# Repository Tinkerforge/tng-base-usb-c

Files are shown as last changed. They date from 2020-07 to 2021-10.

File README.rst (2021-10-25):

TNG Base USB C
==============

**This TNG module is currently in development.**

This repository contains the firmware source code and the hardware design
files. The documentation generator configs can be found at
https://github.com/Tinkerforge/generators

Repository Content
------------------

software/:
 * examples/: Examples for all supported languages
 * build/: Compiled files
 * src/: Source code of firmware
 * Makefile: Makefile to build project

hardware/:
 * Contains KiCad project files and additionally schematics as PDF

datasheets/:
 * Contains datasheets for sensors and complex ICs that are used

Hardware
--------

The hardware is designed with the open source EDA Suite KiCad
(http://www.kicad.org). Before you are able to open the files,
you have to install the Tinkerforge kicad-libraries
(https://github.com/Tinkerforge/kicad-libraries). You can either clone
them directly in hardware/ or clone them in a separate folder and
symlink them into hardware/
(ln -s kicad_path/kicad-libraries project_path/hardware). After that you
can open the .pro file in hardware/ with KiCad and from there view and
modify the schematics and the PCB layout.

Software
--------

If you want to do your own Brick/Bricklet firmware development we highly
recommend that you use our build environment setup script and read the
tutorial (https://www.tinkerforge.com/en/doc/Tutorials/Tutorial_Build_Environment/Tutorial.html).

To compile the C code we recommend you to install the newest GNU Arm Embedded
Toolchain (https://launchpad.net/gcc-arm-embedded/+download).
You also need to install bricklib2 (https://github.com/Tinkerforge/bricklib2).

You can either clone it directly in software/src/ or clone it in a
separate folder and symlink it into software/src/
(ln -s bricklib_path/bricklib2 project_path/software/src/). Finally make sure to
have CMake installed (http://www.cmake.org/cmake/resources/software.html).

After that you can build the firmware by invoking make in software/.
The firmware (.zbin) can then be found in software/build/ and uploaded
with brickv (click button "Flashing" on start screen).

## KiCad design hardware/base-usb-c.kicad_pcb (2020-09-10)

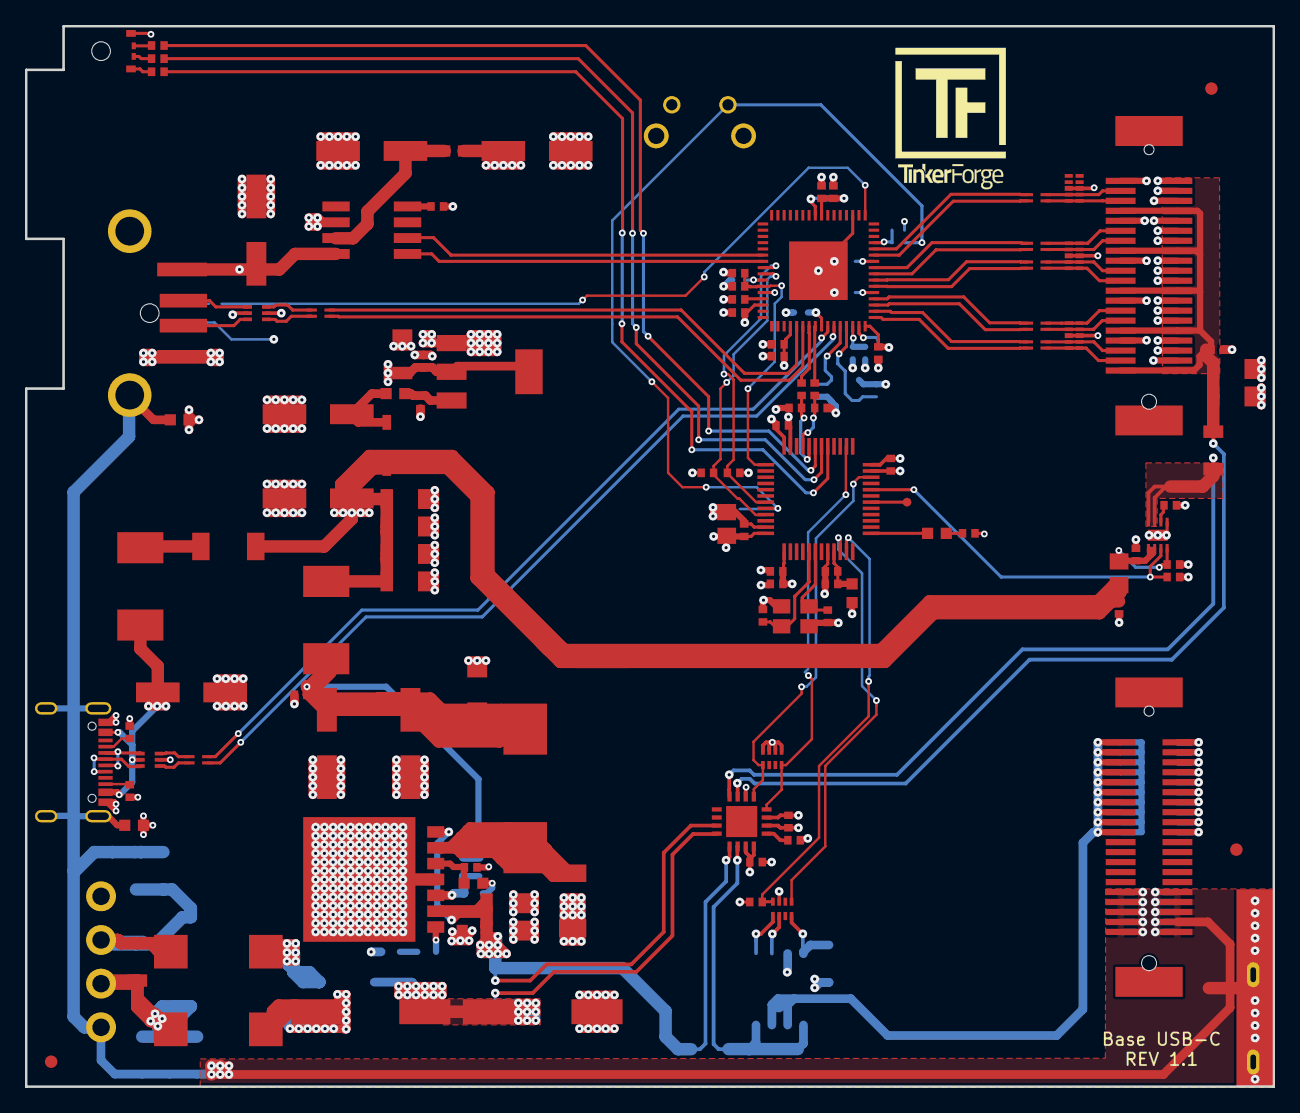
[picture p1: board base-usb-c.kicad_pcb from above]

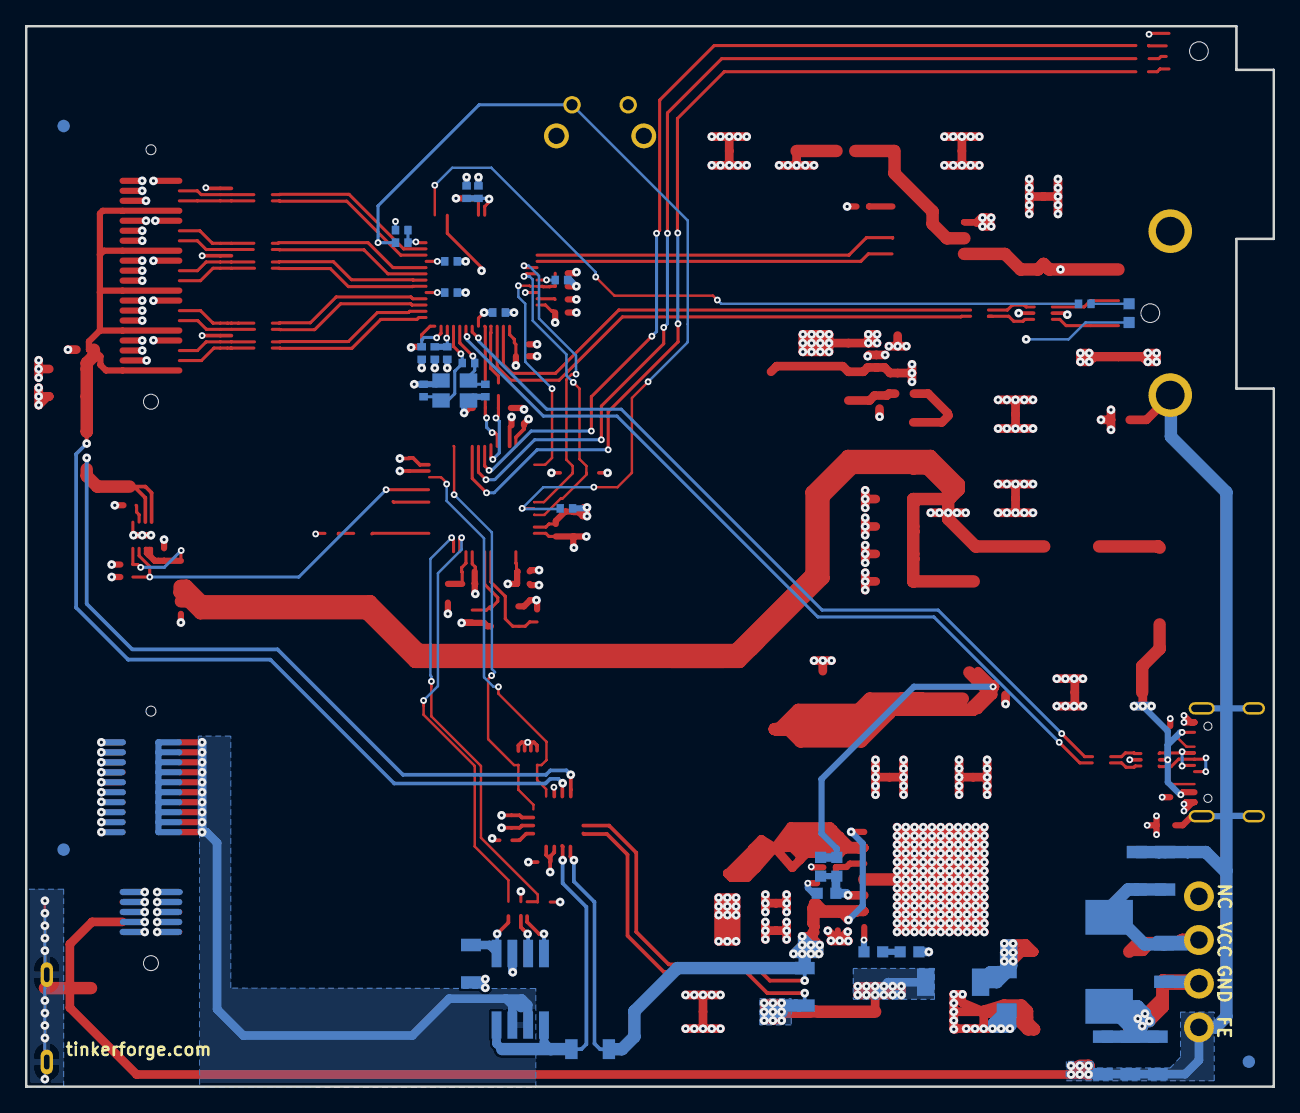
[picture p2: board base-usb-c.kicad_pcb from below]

Board: 4 copper layers, 100.0 x 85.0 mm, 157 parts (39 on the bottom side), 103 nets.

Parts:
C101, C102, C137, C138: 33pF; C0402F
C103, C105, C115, C119, C123, C124, C125, C126, C128, C134, C209, C226: 1uF; C0402F
C104, C106, C107, C110, C111, C112, C113, C114, C116, C118, C127, C129, C130, C131, C133, C214, C221, C222: 100nF; C0402F
C108, C109, C117, C141, C203, C216, C219, C220: 100uF; ELKO_63
C120, C140, C205: 100nF; C0603F
C121, C122: 47pF; C0402F
C132: DNP; C0402F
C135, C136, C201, C202, C215, C218, C223, C224, C225, C227: 10uF; C1206
C139: 10uF; C0805E
C204, C211: 10nF; C1206
C206, C207: 1nF 2kV; C1206
C208: 100pF; C0402F
C210: 4.7nF; C0603F
C212, C213: UWT1H221MNL1GS; ELKO_103
C217: DNP; C0603F
D101: LED green; LED-LP
D102: LED; D0603F
D201: 3.0SMI30CATR; SMC
D202, D205, D206: PMEG6045; SOD-128
D203: B0520LW-7-F; SOD-123
Fiducial_Mark: VAL**; Fiducial_Mark
Fiducial_Mark#2, Fiducial_Mark#3, Fiducial_Mark#4, Fiducial_Mark#5, Fiducial_Mark#6: VAL**; Fiducial_Mark
J101: USB-A; USB-A-SMT-8231
J102: USB-C; USB-C-2
J103: TNG-Power-TOP; TNG-40-TOP
J105: TNG-Data-TOP; TNG-40-TOP
L101, L201: INDUCTs; R0603F
L102, L103, L104, L105, L106, L107, L110: 744230900; WE-CNSW-0603
L108: FB; R0603F
L109: 742792040; R0805E
L111, L203: 10uH; SRP7030
L202: 22uH 74437368220; WE-LHMI
LED101: EASV3015RGBA0; LED-RGB-LP
P101: Debug; DEBUG_PAD
P102: PE; PE_Hook
P202: PWR IN; OQ_4P
R101, R105, R106, R107, R109, R111, R116, R117, R218: 10k; R0402F
R102: 100k; R0402F
R103: 1M; R0402F
R104, R108, R114, R121: 1k; R0402F
R110: 12k; R0402F
R112, R113: 22; R0402F
R115, R119: 0; R0402F
R118: 1k; R1206
R120: 56; R0402F
R122, R123: 5k1; R0402F
R204, R206, R207: VC1206K201R030; R1206
R208: 27k; R0603F
R209: 1M; R1206
R212: 20k; R0603F
R214: 47k; R0603F
R215: 8.2k; R0603F
R219, R220, R221: 0.02; R1206
RP102, RP201: 10k; 4X0402
SW101: BOOT; TACT-6MM-HOR
T201: 744272251; WE-SL5
U101: USB2517; QFN64-9x9mm-0.5mm_USB2517
U102: MIC2026-1YM; SO-8
U103, U108: 82400152; SOT563-SPEC
U104: STM32F070CBT6; LQFP48
U105, U106, U107: TPD4S010DQA
U110: TPS22975; WSON8-2x2
U112: VN7140AS; SO-8
U201: AZ1117EH; SOT-223
U203: BD90640HFP; BD906XX-C-HRP7
U204: PAC1933; QFN-16
X101: 24MHz; CRYSTAL_3225
X102: 8MHz; CRYSTAL_3225

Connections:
3V3: C110.1, C111.1, C112.1, C113.1, C114.1, C115.1, C116.1, C118.1, C119.1, C123.1, C127.1, C129.1, C130.1, C131.1, C139.1, C221.1, C222.1, C226.1, C227.1, D101.1, L108.1, LED101.1, R101.2, R102.2, R106.2, R111.2, R116.2, R117.2, R121.2, RP102.7, RP201.1, RP201.2, RP201.3, RP201.4, SW101.1, U101.5, U101.10, U101.24, U101.44, U101.46, U101.52, U101.57, U101.64, U104.1, U104.24, U104.36, U104.48, U201.2, U204.2, U204.6, U204.15, U204.16
5V_STACK_UP: C134.2, C135.2, C136.2, J105.7, J105.8, J105.15, J105.16, J105.23, J105.24, J105.31, J105.32, J105.39, J105.40, R221.2, U204.7
+5V: C108.1, C125.2, C218.1, C219.1, C223.1, C224.1, C225.1, D202.2, D203.1, L101.2, L109.1, L203.2
BOOT: R108.2, R114.2, SW101.2, U104.44
CTRL_USB_D+: C122.1, R112.2, U104.33
CTRL_USB_D-: C121.1, R113.2, U104.32
CUR1+: C212.1, C213.1, D205.2, R219.1, U204.12
CUR1-: C201.1, C202.1, C205.1, R219.2, R220.1, U203.2, U203.7, U204.11, U204.13
CUR2-: R220.2, U112.5, U112.8, U204.14
CUR3+: R221.1, U110.7, U110.8, U204.8
EXT_USB_D+: L102.1, U101.54
EXT_USB_D-: L102.4, U101.53
EXT_USB_D_F+: J101.3, U103.6
EXT_USB_D_F-: J101.2, U103.4
Earth: C120.1, C140.1, C206.2, C207.1, J101.SHD, J102.SHD, J103.31, J103.32, J103.33, J103.34, J103.35, J103.36, J103.37, J103.38, J103.39, J103.40, P102.1, P202.4, R206.2, R207.1, R209.1
GND: C101.2, C102.2, C103.2, C104.2, C105.2, C106.2, C107.2, C108.2, C109.2, C110.2, C111.2, C112.2, C113.2, C114.2, C115.2, C116.2, C117.2, C118.2, C119.2, C120.2, C121.2, C122.2, C123.2, C124.2, C125.1, C126.1, C127.2, C128.2, C129.2, C130.2, C131.2, C132.2, C133.2, C134.1, C135.1, C136.1, C137.1, C138.1, C139.2, C140.2, C141.2, C201.2, C202.2, C203.2, C205.2, C208.2, C209.2, C210.2, C211.2, C212.2, C213.2, C214.2, C215.2, C216.2, C218.2, C219.2, C220.2, C221.2, C222.2, C223.2, C224.2, C225.2, C226.2, C227.2, D206.1, J101.4, J102.6, J103.2, J103.4, J103.6, J103.8, J103.10, J103.12, J103.14, J103.16, J103.18, J103.20, J105.1, J105.2, J105.4, J105.6, J105.9, J105.10, J105.12, J105.14, J105.17, J105.18, J105.20, J105.22, J105.25, J105.26, J105.28, J105.30, J105.33, J105.34, J105.36, J105.38, R105.1, R107.2, R109.2, R110.1, R114.1, R118.1, R122.1, R123.1, R208.1, R215.1, R218.2, T201.3, U101.19, U101.EXP, U102.6, U103.2, U104.8, U104.23, U104.35, U104.47, U105.3, U105.8, U106.3, U106.8, U107.3, U107.8, U108.2, U110.5, U110.EXP, U112.3, U201.1, U203.4, U203.EXP, U204.3, X101.3, X102.3
LEDB: R120.1, U104.31
LEDG: R119.1, U104.30
LEDR: R115.1, U104.29
unnamed: C101.1, R103.2, U101.61, X101.1
unnamed: C102.1, R103.1, U101.60, X101.2
unnamed: C103.1, C104.1, U101.25
unnamed: C105.1, C106.1, U101.62
unnamed: C109.1, L101.1, U102.7
unnamed: C124.1, C133.1, L108.2, U104.9
unnamed: C126.2, C128.1, L109.2, U110.1, U110.2, U110.4
unnamed: C132.1, U110.6
unnamed: C137.2, U104.5, X102.2
unnamed: C138.2, U104.6, X102.1
unnamed: C141.1, J102.1, L111.2, U108.5
unnamed: C203.1, D203.2, L201.1
unnamed: C204.1, C206.1, D201.1, P202.2, R204.1, R206.1, T201.1
unnamed: C204.2, C207.2, D201.2, P202.3, R204.2, R207.2, R209.2, T201.2
unnamed: C208.1, R208.2, U203.5
unnamed: C209.1, L201.2, U201.3
unnamed: C210.1, R212.1
unnamed: C211.1, D205.1, T201.4
unnamed: C214.1, C215.1, C216.1, C217.1, C220.1, L202.2, L203.1, R214.2
unnamed: C217.2, R214.1, R215.2, U203.3
unnamed: D101.2, R104.2
unnamed: D102.1, R121.1
unnamed: D102.2, U104.13
unnamed: D206.2, L202.1, U203.6
unnamed: J102.2, U108.4
unnamed: J102.3, U108.6
unnamed: J102.4, R123.2
unnamed: J102.5, R122.2
unnamed: L102.2, U103.1
unnamed: L102.3, U103.3
unnamed: L110.2, U108.1
unnamed: L110.3, U108.3
unnamed: LED101.2, R120.2
unnamed: LED101.3, R119.2
unnamed: LED101.4, R115.2
unnamed: P101.1, U104.18
unnamed: R101.1, U101.45
unnamed: R104.1, U101.17
unnamed: R105.2, U102.4
unnamed: R107.1, U101.42
unnamed: R108.1, R109.1, U101.13
unnamed: R110.2, U101.63
unnamed: R112.1, U101.56
unnamed: R113.1, U101.55
unnamed: R118.2, RP102.4, U112.4
unnamed: R212.2, U203.1
unnamed: R218.1, U204.1
unnamed: RP102.1, U112.1
unnamed: RP102.2, U112.2
unnamed: U101.38, U102.2
unnamed: U101.39, U102.1
PAC_SCL: RP201.8, U104.26, U204.4
PAC_SDA: RP201.5, U104.22, U204.5
STACKPWR: J103.1, J103.3, J103.5, J103.7, J103.9, J103.11, J103.13, J103.15, J103.17, J103.19, U112.6, U112.7
STACK_USB_D0+: L103.1, U101.12
STACK_USB_D0-: L103.4, U101.11
STACK_USB_D0_F+: J105.3, L103.2, U105.4, U105.7
STACK_USB_D0_F-: J105.5, L103.3, U105.5, U105.6
STACK_USB_D1+: L104.1, U101.9
STACK_USB_D1-: L104.4, U101.8
STACK_USB_D1_F+: J105.11, L104.2, U106.5, U106.6
STACK_USB_D1_F-: J105.13, L104.3, U106.4, U106.7
STACK_USB_D2+: L105.1, U101.7
STACK_USB_D2-: L105.4, U101.6
STACK_USB_D2_F+: J105.19, L105.2, U106.2, U106.9
STACK_USB_D2_F-: J105.21, L105.3, U106.1, U106.10
STACK_USB_D3+: L106.1, U101.4
STACK_USB_D3-: L106.4, U101.3
STACK_USB_D3_F+: J105.27, L106.2, U107.5, U107.6
STACK_USB_D3_F-: J105.29, L106.3, U107.4, U107.7
STACK_USB_D4+: L107.1, U101.2
STACK_USB_D4-: L107.4, U101.1
STACK_USB_D4_F+: J105.35, L107.2, U107.2, U107.9
STACK_USB_D4_F-: J105.37, L107.3, U107.1, U107.10
SW_5_ENABLE: R116.1, U104.20, U110.3
SW_24_CUR: RP102.5, U104.10
SW_24_ENABLE: R117.1, RP102.8, U104.11
UP_USB_D+: L110.1, U101.59
UP_USB_D-: L110.4, U101.58
USB-PWR: C117.1, J101.1, U102.8, U103.5
USB_RESET: C107.1, R102.1, U101.43, U104.37
USB_SMB_CLK: R111.1, U101.41, U104.45
USB_SMB_DATA: R106.1, U101.40, U104.43
VBUS: D202.1, L111.1

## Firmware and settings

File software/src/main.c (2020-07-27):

/* tng-base-usb-c
 * Copyright (C) 2020 Olaf Lüke <olaf@tinkerforge.com>
 *
 * main.c: Initialization for TNG Base USB C
 *
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
 * You should have received a copy of the GNU Lesser General Public
 * License along with this library; if not, write to the
 * Free Software Foundation, Inc., 59 Temple Place - Suite 330,
 * Boston, MA 02111-1307, USA.
 */

#include "configs/config.h"

#include "bricklib2/tng/tng.h"
#include "bricklib2/logging/logging.h"

#include "driver.h"

int main(void) {
	logging_init();
	logd("Start TNG Base USB C\n\r");

	driver_init();

	while(true) {
		tng_tick();
		driver_tick();
	}
}

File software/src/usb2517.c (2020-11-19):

/* tng-hub
 * Copyright (C) 2020 Olaf Lüke <olaf@tinkerforge.com>
 *
 * usb2517.c: Driver for USB2517 USB hub
 *
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
 * You should have received a copy of the GNU Lesser General Public
 * License along with this library; if not, write to the
 * Free Software Foundation, Inc., 59 Temple Place - Suite 330,
 * Boston, MA 02111-1307, USA.
 */

#include "usb2517.h"

#include "configs/config_usb2517.h"

#include "bricklib2/logging/logging.h"

#define USB_UTF16_LE(ascii) (ascii), 0

#define USB2517_MFR_STR \
	USB_UTF16_LE('T'), USB_UTF16_LE('i'), USB_UTF16_LE('n'), USB_UTF16_LE('k'), USB_UTF16_LE('e'), USB_UTF16_LE('r'), USB_UTF16_LE('f'), USB_UTF16_LE('o'), \
	USB_UTF16_LE('r'), USB_UTF16_LE('g'), USB_UTF16_LE('e'), USB_UTF16_LE(' '), USB_UTF16_LE('G'), USB_UTF16_LE('m'), USB_UTF16_LE('b'), USB_UTF16_LE('H'),

#define USB2517_PRD_STR \
	USB_UTF16_LE('T'), USB_UTF16_LE('N'), USB_UTF16_LE('G'), USB_UTF16_LE('-'), USB_UTF16_LE('B'), USB_UTF16_LE('a'), USB_UTF16_LE('s'), USB_UTF16_LE('e'), \
	USB_UTF16_LE('-'), USB_UTF16_LE('U'), USB_UTF16_LE('S'), USB_UTF16_LE('B'), USB_UTF16_LE('-'), USB_UTF16_LE('C'),

USB2517Memory usb2517_memory = {
	.vid         = 0x4223,              // VID  (0x0424)  // TODO: UPDATE ME!!!
	.pid         = 0x2517,              // PID            // TODO: UPDATE ME!!!
	.did         = 0x0000,              // DID
	.cfg         = {0x9b, 0x20, 0x01},  // Config Data 1-3
	.nrd         = 0x00,                // Non-Removable Devices
	.pds         = 0x00,                // Port Disable (Self)
	.pdb         = 0x00,                // Port Disable (Bus)
	.maxps       = 0x01,                // Max Power (Self)
	.maxpb       = 0x32,                // Max Power (Bus)
	.hcmcs       = 0x01,                // Hub Controller Max Current (Self)
	.hcmcb       = 0x32,                // Hub Controller Max Current (Bus)
	.pwrt        = 0x32,                // Power-on Time
	.langid      = 0x0409,              // Language ID (EN US)
	.mfr_str_len = 16,                  // Manucacturer String Length
	.prd_str_len = 14,                  // Product String Length
	.ser_str_len = 0,                   // Serial Number String Length
	.mfr_str     = {USB2517_MFR_STR},   // Manufacturer String
	.prd_str     = {USB2517_PRD_STR},   // Product String
	.ser_str     = "",                  // Serial Number
	.boostup     = 0x00,                // Boost Up
	.boost75     = 0x00,                // Boost 7:5
	.boost40     = 0x00,                // Boost 4:0
	.prtsp       = 0x00,                // Port Swap
	.prtr12      = 0x00,                // Port Remap 12
	.prtr34      = 0x00,                // Port Remap 34
	.prtr56      = 0x00,                // Port Remap 56
	.prtr7       = 0x00,                // Port Remap 7
	.stcd        = 0x01                 // Status/Command (-> attach)
};

USB2517 usb2517;

void USB2517_SMB_IRQ_HANDLER(void) {
	HAL_SMBUS_EV_IRQHandler(&usb2517.smbus);
	HAL_SMBUS_ER_IRQHandler(&usb2517.smbus);
}

void usb2517_tick(void) {

}

void usb2517_init_smbus(void) {
	// Enable clocks
	RCC_PeriphCLKInitTypeDef rcc = {
		.PeriphClockSelection = USB2517_SMB_RCC_CLK,
		.I2c1ClockSelection = USB2517_SMB_SYS_CLK
	};
	HAL_RCCEx_PeriphCLKConfig(&rcc);
	__HAL_RCC_I2C1_CLK_ENABLE();
	__HAL_RCC_GPIOB_CLK_ENABLE();

	// Configure SDA
	GPIO_InitTypeDef gpio_sda = {
		.Pin       = USB2517_SMB_SDA_PIN,
		.Mode      = GPIO_MODE_AF_OD,
		.Pull      = GPIO_PULLUP,
		.Speed     = GPIO_SPEED_FREQ_HIGH,
		.Alternate = USB2517_SMB_SDA_AF
	};
	HAL_GPIO_Init(USB2517_SMB_SDA_PORT, &gpio_sda);

	// Configure SCL
	GPIO_InitTypeDef gpio_scl = {
		.Pin       = USB2517_SMB_SCL_PIN,
		.Mode      = GPIO_MODE_AF_OD,
		.Pull      = GPIO_PULLUP,
		.Speed     = GPIO_SPEED_FREQ_HIGH,
		.Alternate = USB2517_SMB_SCL_AF
	};
	HAL_GPIO_Init(USB2517_SMB_SCL_PORT, &gpio_scl);

	HAL_NVIC_SetPriority(USB2517_SMB_IRQ, 0, 0);
	HAL_NVIC_EnableIRQ(USB2517_SMB_IRQ);

	usb2517.smbus.Instance                  = USB2517_SMB_INSTANCE;
	usb2517.smbus.Init.Timing               = USB2517_SMB_TIMING;
	usb2517.smbus.Init.AnalogFilter         = SMBUS_ANALOGFILTER_ENABLE;
	usb2517.smbus.Init.OwnAddress1          = 0x00;
	usb2517.smbus.Init.AddressingMode       = SMBUS_ADDRESSINGMODE_7BIT;
	usb2517.smbus.Init.DualAddressMode      = SMBUS_DUALADDRESS_DISABLE;
	usb2517.smbus.Init.OwnAddress2          = 0x00;
	usb2517.smbus.Init.GeneralCallMode      = SMBUS_GENERALCALL_DISABLE;
	usb2517.smbus.Init.NoStretchMode        = SMBUS_NOSTRETCH_DISABLE;  
	usb2517.smbus.Init.PacketErrorCheckMode = SMBUS_PEC_DISABLE;
	usb2517.smbus.Init.PeripheralMode       = SMBUS_PERIPHERAL_MODE_SMBUS_HOST;
	usb2517.smbus.Init.SMBusTimeout         = 0;

	HAL_StatusTypeDef status;
	if((status = HAL_SMBUS_Init(&usb2517.smbus)) != HAL_OK) {
		loge("HAL_SMBUS_Init Error %d\n\r", status);
	}
}

void usb2517_init(void) {
	usb2517_init_smbus();

	// USB Reset
	__HAL_RCC_GPIOA_CLK_ENABLE();
	GPIO_InitTypeDef gpio_usb_reset = {
		.Pin   = USB2517_RESET_PIN,
		.Mode  = GPIO_MODE_OUTPUT_PP,
		.Speed = GPIO_SPEED_FREQ_LOW
	};
	HAL_GPIO_Init(USB2517_RESET_PORT, &gpio_usb_reset);

	HAL_GPIO_WritePin(USB2517_RESET_PORT, USB2517_RESET_PIN, GPIO_PIN_RESET);
	system_timer_sleep_ms(10);
	HAL_GPIO_WritePin(USB2517_RESET_PORT, USB2517_RESET_PIN, GPIO_PIN_SET);
	system_timer_sleep_ms(10);

	logd("Start initial USB hub code load (%d bytes)\n\r", sizeof(USB2517Memory));
	for(uint8_t i = 0; i < sizeof(USB2517Memory)/16; i++) {
		uint8_t data[18] = {i*16, 16};
		memcpy(&data[2], ((uint8_t *)&usb2517_memory) + i*16, 16);
		HAL_StatusTypeDef status;
		if((status = HAL_SMBUS_Master_Transmit_IT(&usb2517.smbus, USB2517_SMB_ADDRESS, data, 18, SMBUS_FIRST_AND_LAST_FRAME_NO_PEC)) != HAL_OK) {
			loge("HAL_SMBUS_Master_Transmit_IT Error %d\n\r", status);
		}

		// TODO: Add Timeout?
		while(HAL_SMBUS_GetState(&usb2517.smbus) != HAL_SMBUS_STATE_READY);
	}
}

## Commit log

2020-08-25 version 1.1
    * fix usb-c cc resistors
    [base-usb-c.kicad_pcb, base-usb-c.sch]
2020-09-04 add version 1.1
    fix usb c
    fix footprints
    [base-usb-c.kicad_pcb, base-usb-c.sch, power.sch]
2020-09-07 fix values
    [base-usb-c.kicad_pcb, base-usb-c.sch, power.sch]
2020-09-07 fix value
    [base-usb-c.kicad_pcb, base-usb-c.sch]
2020-09-07 small changes
    [base-usb-c.kicad_pcb, base-usb-c.sch]
2020-09-07 fix footprint
    [base-usb-c.kicad_pcb, base-usb-c.sch]
2020-09-08 all footprints updated
    [base-usb-c.kicad_pcb]
2020-09-09 fix outline
    [base-usb-c.kicad_pcb]
2020-09-10 fix usb positon, fix 3d
    [base-usb-c.kicad_pcb]
2021-10-25 Update KiCad link
    https://www.kicad.org/blog/2021/10/Avoid-links-to-former-kicad-domain/

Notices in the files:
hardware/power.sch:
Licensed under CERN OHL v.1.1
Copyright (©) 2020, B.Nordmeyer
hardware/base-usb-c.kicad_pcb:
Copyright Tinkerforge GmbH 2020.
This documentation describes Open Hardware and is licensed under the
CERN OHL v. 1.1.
